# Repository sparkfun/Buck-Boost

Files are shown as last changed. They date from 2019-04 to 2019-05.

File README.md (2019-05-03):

SparkFun Buck-Boost Converter
========================================

SparkFun Buck-Boost Converter

[*SparkFun Buck-Boost Converter (15208)*](https://www.sparkfun.com/products/15208)

<Basic description of the part.>

Repository Contents
-------------------

* **/Hardware** - Eagle design files (.brd, .sch)

Documentation
--------------
* **[Hookup Guide](https://learn.sparkfun.com/tutorials/buck-boost-hookup-guide)** - Basic hookup guide for the SparkFun Buck-Boost Converter.

License Information
-------------------

This product is _**open source**_!

Please review the LICENSE.md file for license information.

If you have any questions or concerns on licensing, please contact technical support on our [SparkFun forums](https://forum.sparkfun.com/viewforum.php?f=152).

Distributed as-is; no warranty is given.

- Your friends at SparkFun.

_<COLLABORATION CREDIT>_

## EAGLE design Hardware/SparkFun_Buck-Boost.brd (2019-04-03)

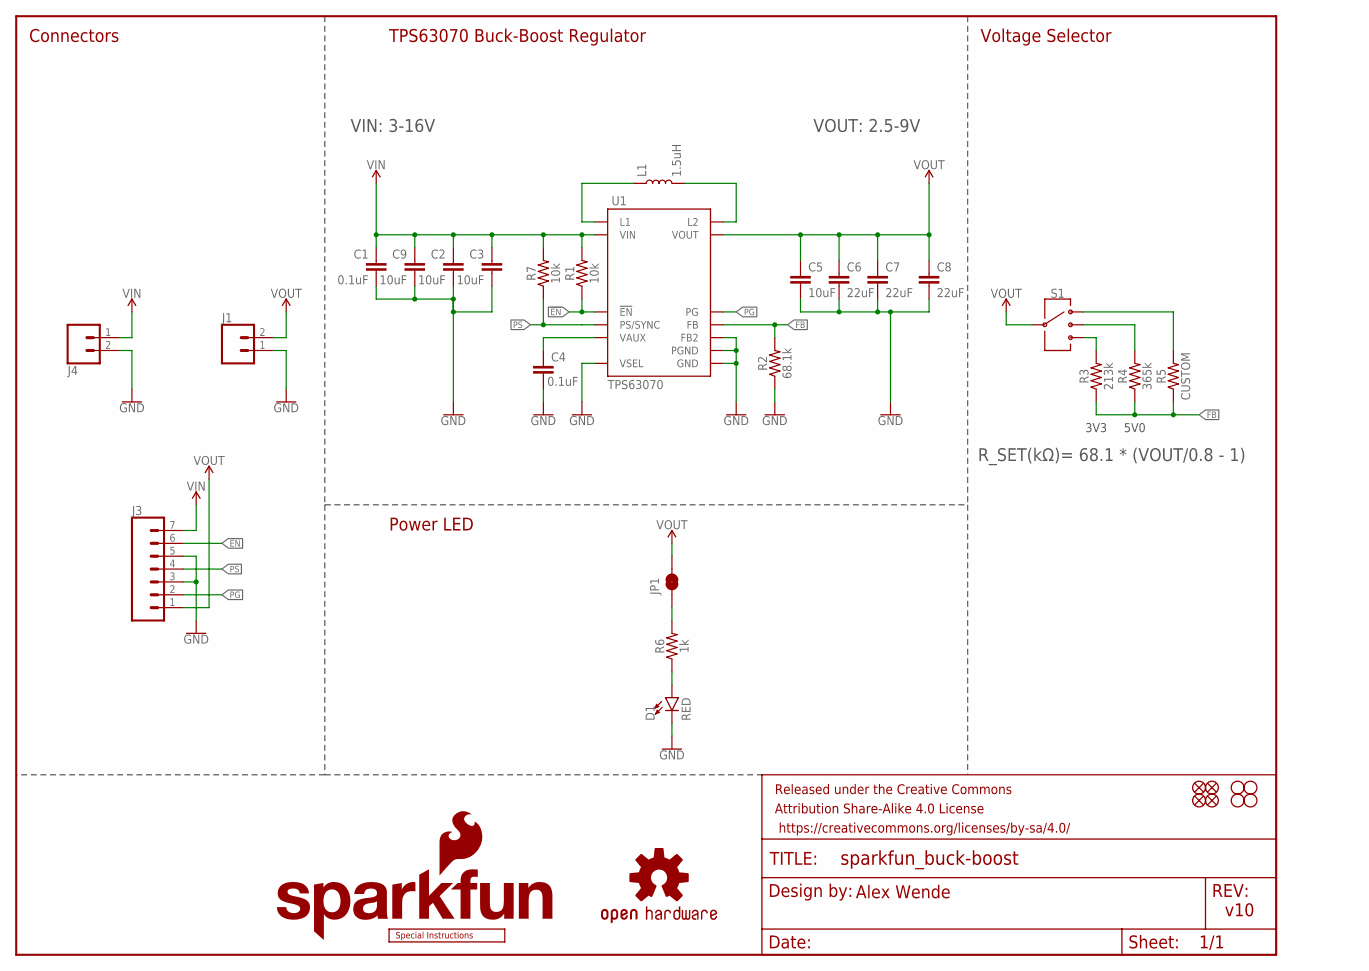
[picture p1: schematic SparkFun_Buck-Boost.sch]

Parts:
C1, C4: 0.1uF; 0603
C2, C3, C5, C9: 10uF; 0805
C6, C7, C8: 22uF; 0805
D1: RED; LED-0603
FD1, FD2, FD3, FD4: FIDUCIALUFIDUCIAL; FIDUCIAL-MICRO
FRAME1: FRAME-LETTER; CREATIVE_COMMONS
H1, H2, H3, H4: STAND-OFF
J1, J4: CONN_023.5MM-NO_SILK; SCREWTERMINAL-3.5MM-2-NS
J3: CONN_07NO_SILK; 1X07_NO_SILK
JP1: JUMPER-SMT_2_NC_TRACE_NO-SILK; SMT-JUMPER_2_NC_TRACE_NO-SILK
L1: 1.5uH; XFL4020
LOGO1: SFE_LOGO_NAME_FLAME.1_INCH; SFE_LOGO_NAME_FLAME_.1
LOGO2: OSHW-LOGOS; OSHW-LOGO-S
LOGO3: SPECIAL_INSTRUCTIONS-ORDERING; ORDERING_INSTRUCTIONS
R1, R7: 10k; 0603
R2: 68.1k; 0603
R3: 213k; 0603
R4: 365k; 0603
R5: CUSTOM; AXIAL-0.3
R6: 1k; 0603
S1: SWITCH-SP3T-SMD; SWITCH_SP3T_SMD
U1: TPS63070; VQFN-15-HR(3X2.5)

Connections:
!EN: J3.6, R1.1, U1.P$14 (!EN)
FB: R2.2, R3.1, R4.1, R5.P$1 (1), U1.P$5 (FB)
GND: C1.2, C2.2, C3.2, C4.2, C5.2, C6.2, C7.2, C8.2, C9.2, D1.C, J1.1, J3.3, J3.5, J4.2, R2.1, U1.P$4 (GND), U1.P$6 (FB2), U1.P$10 (PGND), U1.P$15 (VSEL)
unnamed: L1.P$1 (1), U1.P$11 (L1)
unnamed: L1.P$2 (2), U1.P$9 (L2)
unnamed: R5.P$2 (2), S1.1
unnamed: R4.2, S1.2
unnamed: C4.1, U1.P$3 (VAUX)
unnamed: R3.2, S1.4
unnamed: JP1.1, R6.2
unnamed: D1.A, R6.1
PG: J3.2, U1.P$2 (PG)
PS: J3.4, R7.1, U1.P$1 (PS/SYNC)
VIN: C1.1, C2.1, C3.1, C9.1, J3.7, J4.1, R1.2, R7.2, U1.P$12/13 (VIN)
VOUT: C5.1, C6.1, C7.1, C8.1, J1.2, J3.1, JP1.2, S1.3, U1.P$7/8 (VOUT)

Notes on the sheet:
v10
Alex Wende
Connectors
TPS63070 Buck-Boost Regulator
Voltage Selector
VIN: 3-16V
VOUT: 2.5-9V
R_SET(kΩ)= 68.1 * (VOUT/0.8 - 1)
Power LED
3V3
5V0

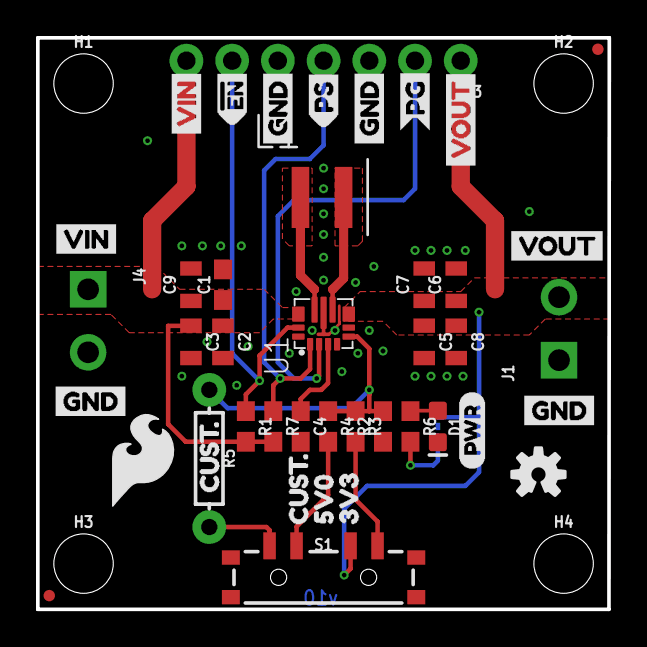
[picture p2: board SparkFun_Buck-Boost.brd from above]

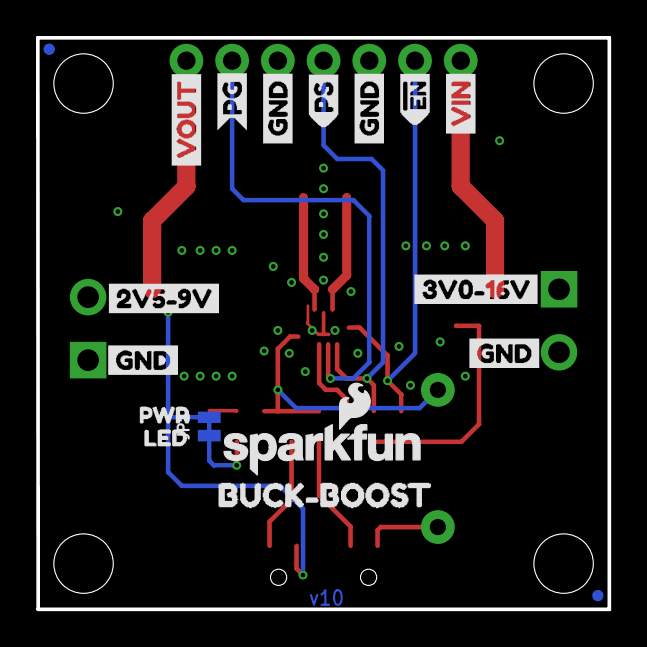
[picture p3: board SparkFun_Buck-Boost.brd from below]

Board: 2 copper layers, 31.8 x 31.8 mm, 67 parts (18 on the bottom side), 15 nets.

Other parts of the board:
U$1: PWR2
U$2, U$17: CUST#7
U$3, U$25: VIN0
U$4, U$20, U$30, U$31: GND1
U$5: VIN3
U$6, U$7, U$12, U$13: GND4
U$8: VOUT5
U$9: SFE_LOGO_FLAME_.2
U$10: 3V0#16V6
U$11: PWR1
U$14: 2V5#9V1
U$15: BUCK#BOOST18
U$16: LED0
U$18: 5V08
U$19: 3V39
U$21, U$26: VOUT2
U$22, U$28: #EN0
U$23, U$29: PS1
U$24, U$27: PG2

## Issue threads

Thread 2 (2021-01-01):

EN disabled - High current consumption

adamgarbo, 2021-01-01:
Hi folks,

I'm not sure if the SparkFun Buck-Boost will ever see any hardware revisions, but I thought I'd report an issue and make a suggestion that doesn't require any modifications to the board, just a different resistance value.

When the Buck-Boost is disabled by pulling the EN pin LOW, the quiescent draw jumps significantly. This is due to the 10 kΩ pull-up resistor on the EN pin. For example, 5 V = 0.5 mA, 12 V = 1.2 mA. By comparison, the TPS63070 has a shut-down current of 2 uA.

The TPS63070 datasheet also states that "It is recommended to not connect EN directly to VIN but use a resistor in series in the range of 1kΩ to 1MΩ."

If the pull-up resistor was increased to 1MΩ, this would decrease the quiescent draw considerably (5 V = 5 uA and 12 V = 12 uA.

Is this something SparkFun could do in house?

Cheers,
Adam

P.S. Originally reported here: https://forum.sparkfun.com/viewtopic.php?f=103&t=54433&p=221143#p221143

adamgarbo, 2021-12-23:
Closing as the Buck-Boost is unlikely to see a hardware revision. The new [SparkFun BabyBuck](https://www.sparkfun.com/products/18357) also provides a more power-efficient alternative (only for 3.3V).

Closed 2021-12-23.

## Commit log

2019-01-30 Design Review Changes
    -Moved standoffs 0.1" offset
    -Added power LED with jumper to output
    -Added vias under IC1
    -Added units to measures layer
    [2A_Buck_Boost.brd, 2A_Buck_Boost.sch]
2019-01-30 QC Fixes
    -Fixed board dimention width
    -Fixed feedback resistor equation
    -Adjusted power led silk
    -Adjusted VIN copper pour to line up with C1 tstop
    [2A_Buck_Boost.brd, 2A_Buck_Boost.sch]
2019-03-29 V10 changes
    - Added note for 2oz copper
    - Replace power connections with 3.5mm screw terminals
    [SparkFun_Buck-Boost.brd, SparkFun_Buck-Boost.sch]
2019-04-03 Updated BOM
    Replaced 357k resistor with 365k resistor
    [SparkFun_Buck-Boost.brd, SparkFun_Buck-Boost.sch]
2019-04-29 Formatting repo
    [SparkFun_Buck-Boost.brd, SparkFun_Buck-Boost.sch]

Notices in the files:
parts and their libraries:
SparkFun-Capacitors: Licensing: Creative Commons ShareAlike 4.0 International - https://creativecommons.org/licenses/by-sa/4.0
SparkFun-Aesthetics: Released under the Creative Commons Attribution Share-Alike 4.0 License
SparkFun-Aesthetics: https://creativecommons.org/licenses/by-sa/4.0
